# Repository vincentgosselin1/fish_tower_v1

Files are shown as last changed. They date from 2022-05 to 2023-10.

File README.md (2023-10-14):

# fish_tower_v1
fish_tower_v1\
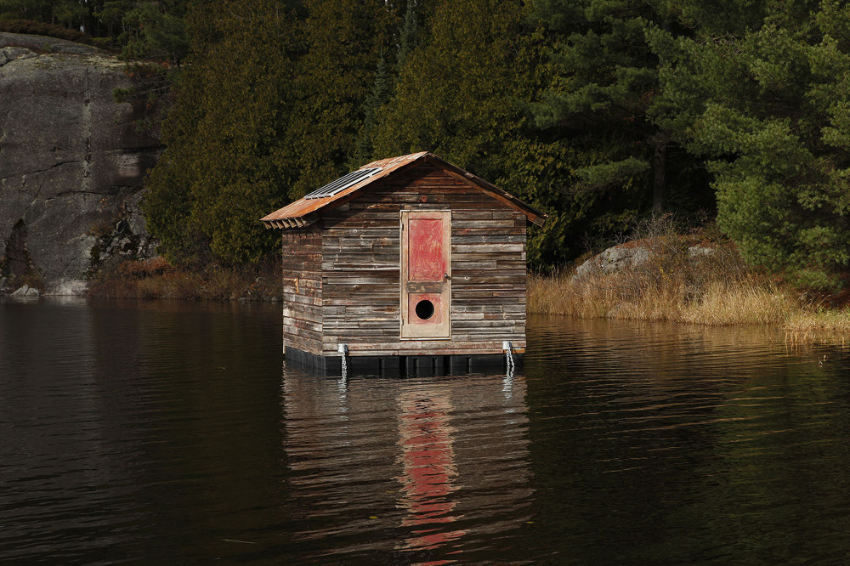
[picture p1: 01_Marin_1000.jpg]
\
all details in https://www.carlmarin.com/Meeting-Point \
Electronic circuit inside : \
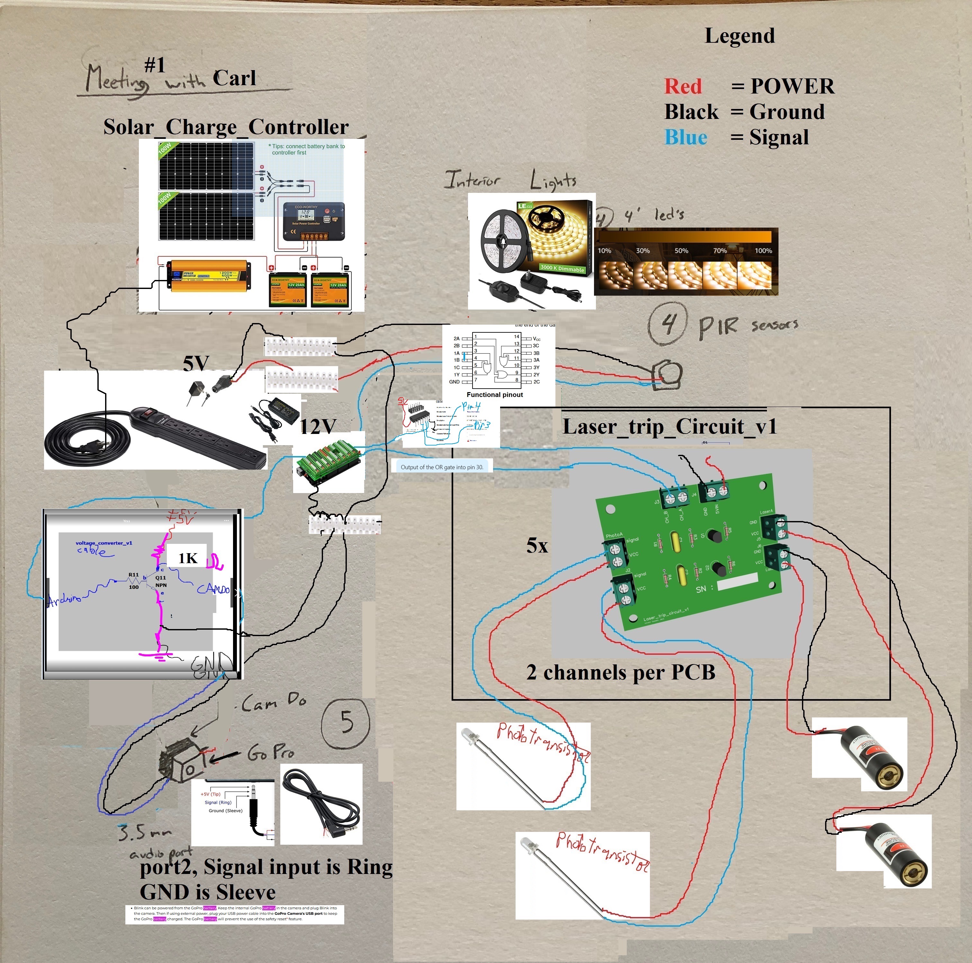
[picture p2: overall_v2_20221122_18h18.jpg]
 \
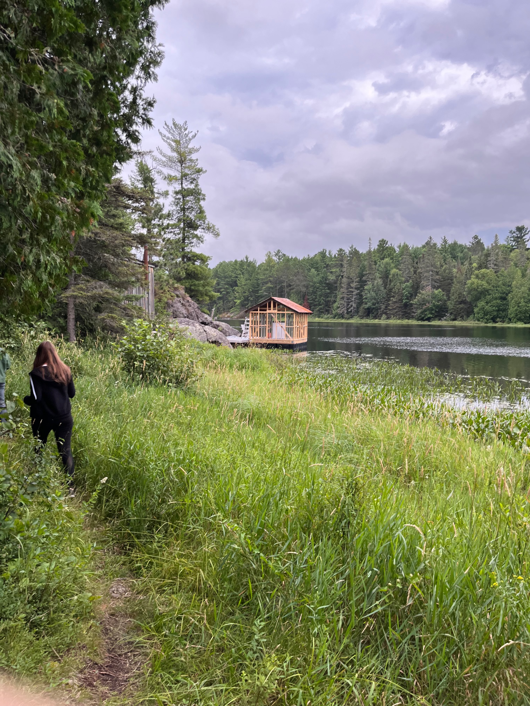
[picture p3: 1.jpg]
 \
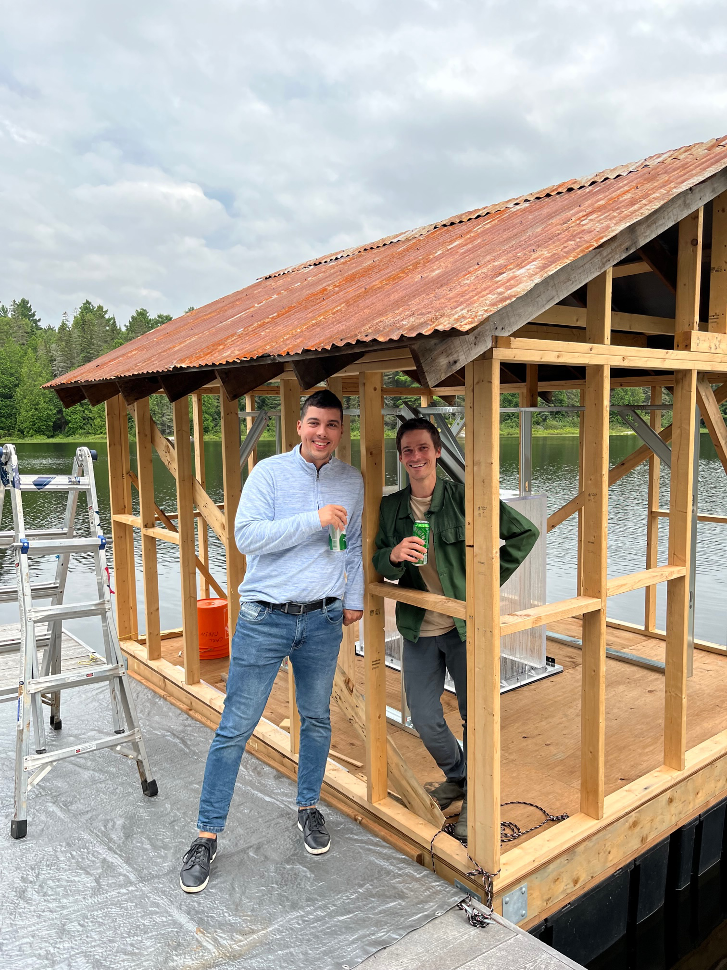
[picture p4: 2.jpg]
 \
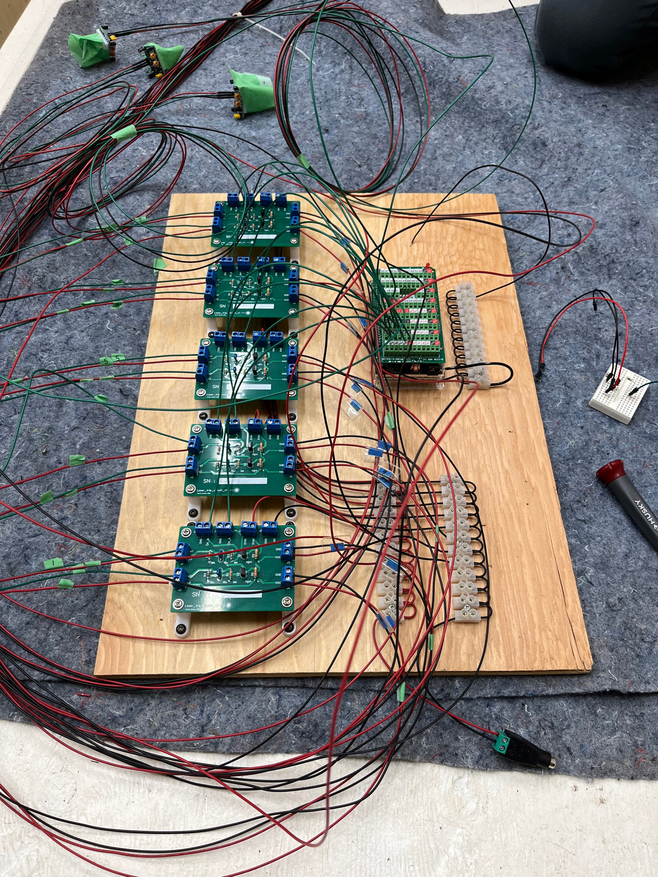
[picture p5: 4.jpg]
 \
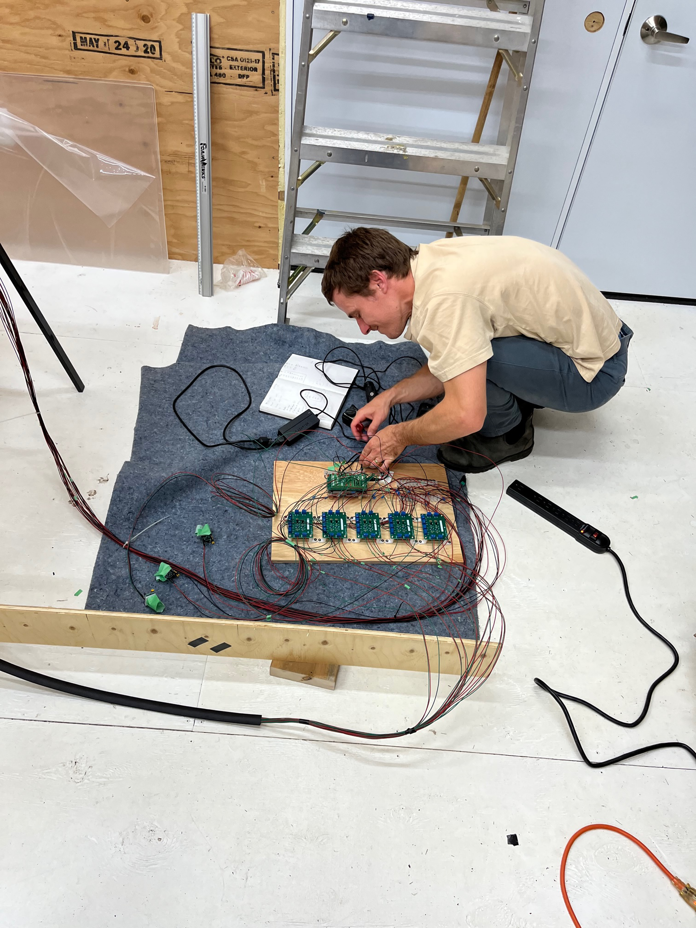
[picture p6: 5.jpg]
 \

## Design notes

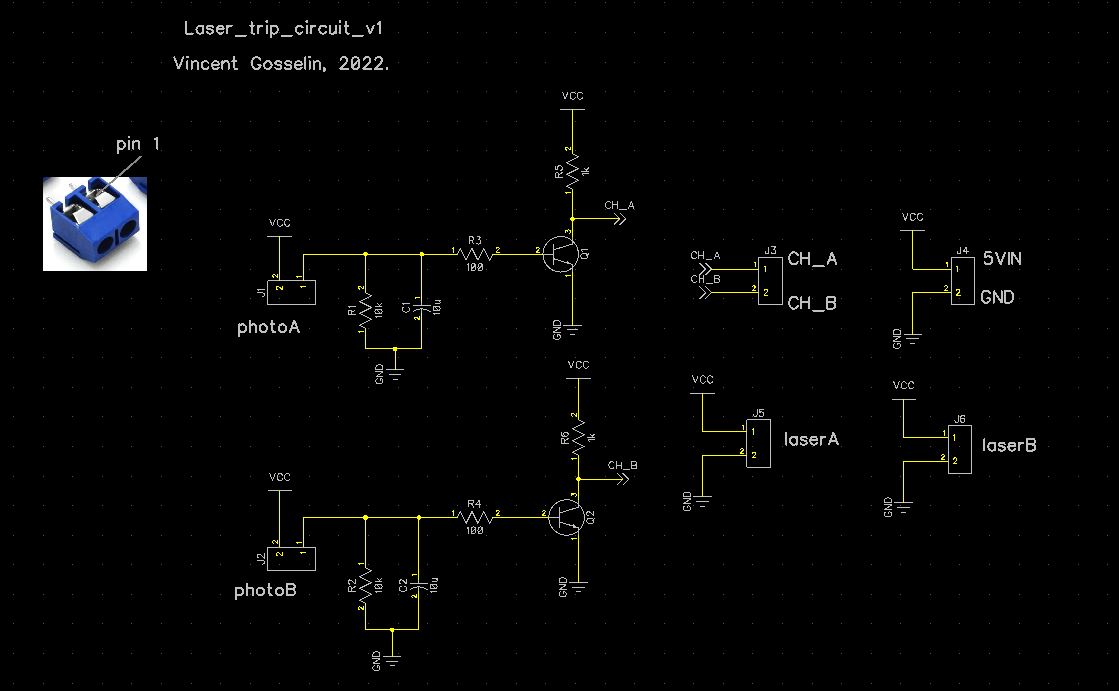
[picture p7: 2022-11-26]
Laser_trip_circuit_v1/laser_trip_circuit_v1_SCHEMATIC.JPG

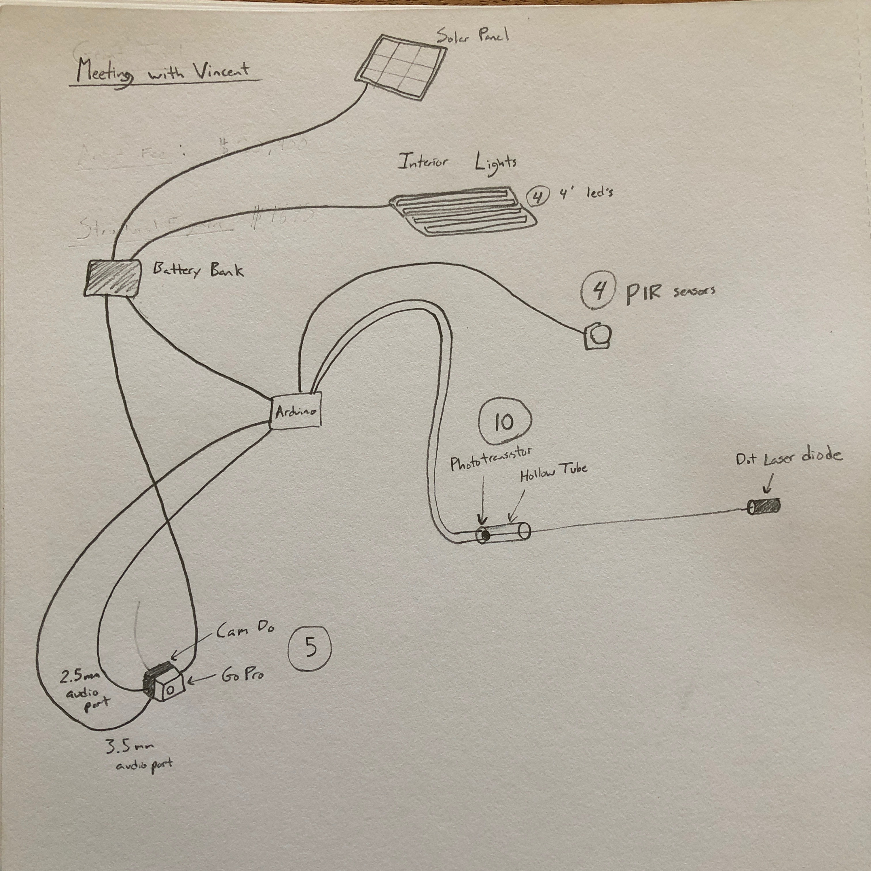
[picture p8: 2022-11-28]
goodtimes/Carl_design.jpeg

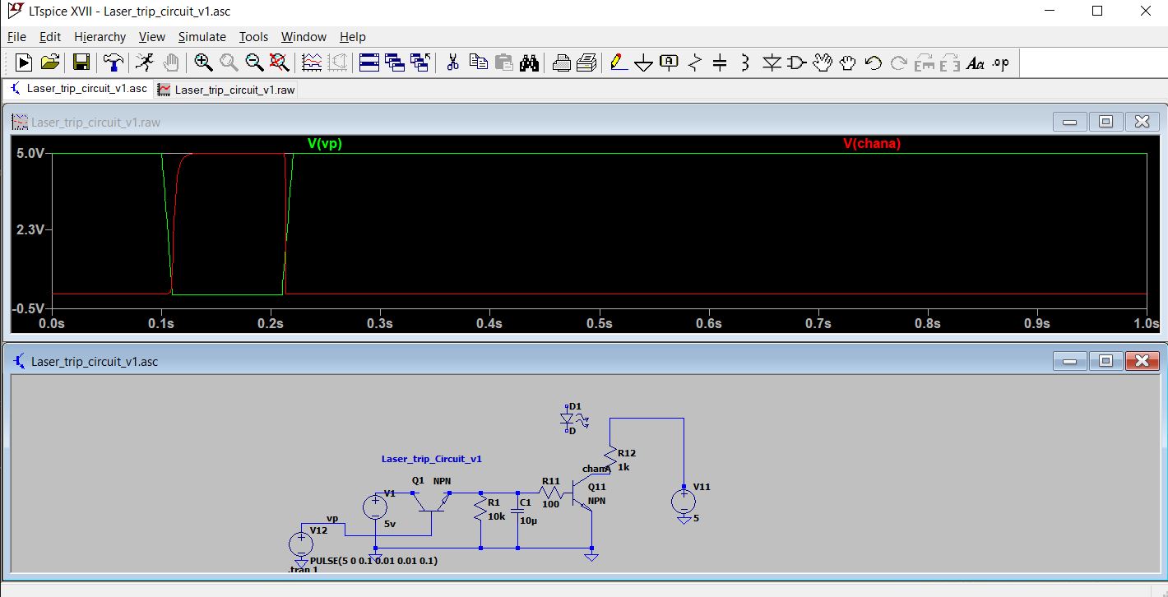
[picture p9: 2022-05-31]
Laser_trip_circuit_v1.JPG

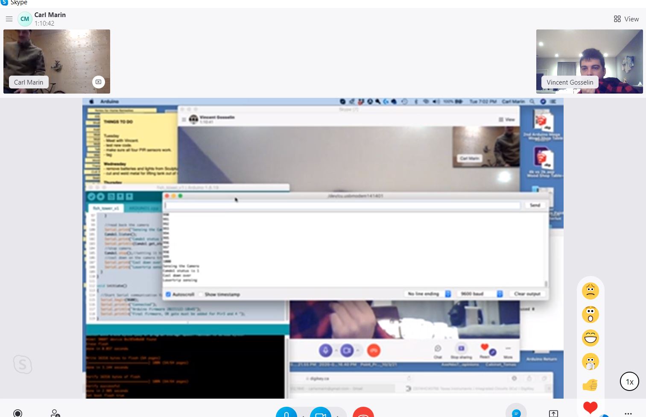
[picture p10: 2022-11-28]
goodtimes/goodtimes5.JPG

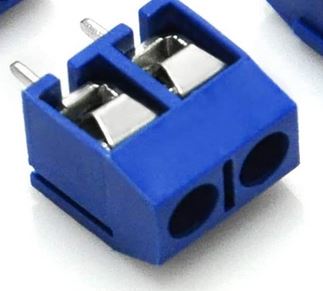
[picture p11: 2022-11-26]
Laser_trip_circuit_v1/pic1.JPG

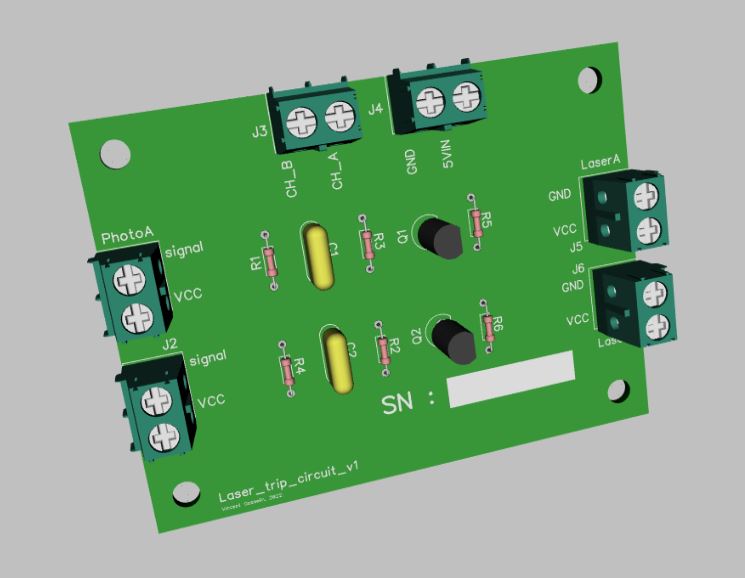
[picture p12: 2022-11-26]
Laser_trip_circuit_v1/laser_trip_circuit_v1_3d.JPG

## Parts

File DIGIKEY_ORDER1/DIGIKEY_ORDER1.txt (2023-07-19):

#DIGIKEY_ORDER1
#CART LINK : https://www.digikey.ca/short/zj1rfh8n

1. Phototransistor : 1080-1019-ND x20
2.  red laser : 		1528-1391-ND x11
2.1 resistor 100 : A105980CT-N
3.  resistors 1k : check	
4.  resistors 10k : check 
5.  capacitor 1uF :  check
6.  capacitor 10uF : check
7.  buzzer :   check
7.1 Arduino Mega : (Amazon order)

8.  potentiometer 1k : check 

9.  ON/OFF switch : check 

11. 5VDC Brick barrel: check

10. phenix terminal bloc : (todo)

11. Laptop 12VDC Brick barrel: (not sure)

11.1 dc barel jack to wires : (check)
12. jumper wires male/male (not sure)

13. variable temperature soldering iron (check)
14. Tin metal : (check)

15. npn transistors : (check)
15. diodes. (check)
16. 12V to 9V DC regulator (todo)
16.1 12V to 5V DC regultator (todo)

17. cable shrink (check)
18. leds  (check)
19.  simple solid core wire 22 awg. (check)
	-> Blue (green instead)
	-> Black
	-> Red

20. electrical tape (check)

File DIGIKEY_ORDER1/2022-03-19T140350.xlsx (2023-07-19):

Index | Quantity | Part Number | Manufacturer Part Number | Description | Customer Reference | Available | Backorder | Unit Price | Extended Price CAD
1 | 20 | 1080-1019-ND | ALS-PT204-6C/L177 | SENSOR PHOTO 630NM RADIAL |  | 20 | 0 | 0.582 | 11.64
2 | 11 | 1528-1391-ND | 1054 | LASER DIODE 650NM 5MW 10MM DIA |  | 11 | 0 | 8.72 | 95.92
3 | 50 | A105980CT-ND | CFR16J100R | RES 100 OHM 5% 1/4W AXIAL |  | 50 | 0 | 0.064 | 3.20
4 | 50 | 1.0KQBK-ND | CFR-25JB-52-1K | RES 1K OHM 5% 1/4W AXIAL |  | 50 | 0 | 0.0534 | 2.67
5 | 50 | 10KEBK-ND | CFR-12JB-52-10K | RES 10K OHM 5% 1/6W AXIAL |  | 50 | 0 | 0.059 | 2.95
6 | 15 | 490-9146-1-ND | RDER71H105K2M1H03A | CAP CER 1UF 50V X7R RADIAL |  | 15 | 0 | 0.623 | 9.35
7 | 15 | 445-FK26X7R1E106K-ND | FK26X7R1E106K | CAP CER 10UF 25V X7R RADIAL |  | 15 | 0 | 0.707 | 10.61
8 | 3 | 445-5242-1-ND | PS1440P02BT | BUZZER PIEZO 3V 14MM TH |  | 3 | 0 | 1.01 | 3.03
9 | 3 | 987-1736-ND | P160KNPD-4QA15A5K | POT 5K OHM 1/10W PLASTIC LOG |  | 3 | 0 | 1.18 | 3.54
10 | 3 | EG5693-ND | RR3112ABLKBLKNFF0 | SWITCH ROCKER SPST 16A 125V |  | 3 | 0 | 1.8 | 5.40
11 | 1 | 839-1662-ND | 16-00019 | AC/DC WALL MOUNT ADAPTER 5V 5W |  | 1 | 0 | 11.74 | 11.74
12 | 1 | 1568-1510-ND | PRT-10288 | ADAPT TERM BL 2POS TO 2.1MM JCK |  | 1 | 0 | 4.06 | 4.06
13 | 1 | 19-165BK4A-ND | 165BK4A | TAPE ELECTRICAL BK 3/4"X 60' |  | 1 | 0 | 4.66 | 4.66
14 | 1 | 1175-2668-50-ND | 10982-22-1-2000-001-1-TD | HOOK-UP SOLID 22AWG 300V BLK 50' |  | 1 | 0 | 11.62 | 11.62
15 | 1 | 1175-2683-50-ND | 10982-22-1-2000-007-1-TD | HOOK-UP SOLID 22AWG 300V GRN 50' |  | 1 | 0 | 11.62 | 11.62
16 | 1 | 1175-2669-50-ND | 10982-22-1-2000-004-1-TD | HOOK-UP SOLID 22AWG 300V RED 50' |  | 1 | 0 | 11.62 | 11.62
17 | 1 | 2260-AO469-ND | AO469 | 60 WATT SOLDERING STATION |  | 1 | 0 | 43.57 | 43.57
18 | 2 | RASW.031.7OZ-ND | RASW.031 .7OZ | SOLDER WIRE POCKET PACK 63/37 TI |  | 2 | 0 | 6.47 | 12.94
19 | 20 | PN2222AFS-ND | PN2222ABU | TRANS NPN 40V 1A TO92-3 |  | 20 | 0 | 0.383 | 7.66
20 | 10 | 754-1807-ND | WP7113VBC/D | LED BLUE CLEAR T-1 3/4 T/H |  | 10 | 0 | 0.525 | 5.25
21 | 1 | Q2Z1-KIT-ND | Q2-Z-QK1-01-6IN-180 | HEATSHRNK KIT 6" 3/64-1/4" 180PC |  | 1 | 0 | 35.64 | 35.64
22 | 1 | 243-1183-ND | 17536 | DESOLDER PUMP WITH TIP 7.5" |  | 1 | 0 | 10.85 | 10.85

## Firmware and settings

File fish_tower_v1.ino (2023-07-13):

/* 
fish_tower_v1.ino, Vincent Gosselin 2023.

FishTower project. 

Target hardware : Arduino Due

Description:

There are 10x laser_trip_circuit hooked to the arduino
to trigger the 5x Camdoo cameras. The Camdoo camera have a feedback signal.
The cameras can also be triggered by 5x PIR sensors. 


Version: 1.o

boot up sequence should be
1. 12V
2. USB cable
3. 5V
4. Camdoo

*/

#include "ARDUINO1.h"
#include "arduinotools.h"

//ALL CLASSES ARE FROM ARDUINO1

//Components
Lasertrip Lasertrip1A(13); //pin13 lasertrip pcb1 with channel A.
Lasertrip Lasertrip1B(12); //pin12 lasertrip pcb1 with channel B.
Lasertrip Lasertrip2A(11); 
Lasertrip Lasertrip2B(10); 
Lasertrip Lasertrip3A(9);
Lasertrip Lasertrip3B(8);
Lasertrip Lasertrip4A(7);
//Lasertrip Lasertrip4B(6);
//Lasertrip Lasertrip5A(5);
Lasertrip Lasertrip5B(4);

Camdo Camdo1(35,37); //Camdo #1, pin 35 trigger 3.5mm , pin 37 feedback 2.5mm.

//PIR_sensor PIR_sensor1(28);
//PIR_sensor PIR_sensor2(29);
//PIR_sensor PIR_sensor3(30);

SmartWait SmartWait1;

void setup()
{
  initiate();
}

void loop()
{
  //turn OFF camdoo
  Camdo1.stop();
  
  //listen to lasertrip circuits
  Lasertrip1A.listen();
  Lasertrip1B.listen();
  Lasertrip2A.listen();
  Lasertrip2B.listen();
  Lasertrip3A.listen();
  Lasertrip3B.listen();
  Lasertrip4A.listen();
  //Lasertrip4B.listen();
  //Lasertrip5A.listen();
  Lasertrip5B.listen();
  //PIR_sensor1.listen();
  //PIR_sensor2.listen();
  //PIR_sensor3.listen();
  
  //Did an event happenned?
    if(    Lasertrip1A.get_status() || Lasertrip1B.get_status() 
	   || Lasertrip2A.get_status() || Lasertrip2B.get_status() 
	   || Lasertrip3A.get_status() || Lasertrip3B.get_status()
	   || Lasertrip4A.get_status() || Lasertrip5B.get_status()
	   //|| PIR_sensor1.get_status() || PIR_sensor2.get_status()
	   //|| PIR_sensor3.get_status() 
         ){
    
    //a fish was detected! 
    Serial.print("a fish was detected!, laser tripped!  \n\r");
    //activate the camera
    Serial.print("Activating the Camera \n\r");
    Camdo1.run();//setting it low
    
    int i = 0;
    while(i<1000){
      i++;
      Serial.println(i, DEC);
    }
    
    //read back the camera
    Serial.print("Sensing the Camera \n\r");
    Camdo1.listen();
    Serial.print("Camdo1 status is ");
    Serial.println(Camdo1.get_status());
    //stop camera.
    Camdo1.stop();//setting it high
    //cool down on the camera trigger
    delay(210000);//3 mins 30 seconds
    Serial.print("Cool down over \n\r");
    Serial.print("Lasertrip sensing \n\r");
  }
}

void initiate()
{
	//Start Serial communication for debugging.
	Serial.begin(9600);
	Serial.println("Connected");
	Serial.println("Arduino firmware 20230712-19h59");
	Serial.println("pir sensors and laser4B/5A de-activated");
}

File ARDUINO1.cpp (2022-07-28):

//GROWBOX1 Library, defitions of class.
//Growbox1_arduinodue Software by Vincent Gosselin, copyright 2016.	

//This File should copied to Documents/Arduino/Libraries/GROWBOX1/GROWBOX1.cpp for changes to happen in the Arduino.


//#include "Arduino.h"
#include "ARDUINO1.h"
//Digital pin class.
Digital_pin::Digital_pin(int pin)
{
	_pin=pin;
	_state=0;//LOW at init.
	_previousMillis=0;//0 a start;
}
bool Digital_pin::get_state()
{
	return _state;
}
void Digital_pin::set_input()
{
	pinMode(_pin,INPUT);
}
void Digital_pin::set_input_pullup()
{
	pinMode(_pin,INPUT_PULLUP);
}
void Digital_pin::set_output()
{
	pinMode(_pin,OUTPUT);
}
void Digital_pin::high()
{
	digitalWrite(_pin,1);
	_state=1;
}
void Digital_pin::low()
{
	digitalWrite(_pin,0);
	_state=0;
}
void Digital_pin::blink()
{
	unsigned long currentMillis = millis();
	if(currentMillis - _previousMillis >= 300)
	{
		_previousMillis = currentMillis;
		digitalWrite(_pin,_state);
		_state=!_state;
	}
	else;
}
void Digital_pin::init()
{
	set_output();
	low();
}
bool Digital_pin::read_input()
{
	bool state;
	state = digitalRead(_pin);
	_state = state;
	return state;
}
//led class
led::led(int pin)
{
	_pin = new Digital_pin(pin);//Creating object Digital_pin.
	_pin->set_output();//Pin will be an output.
	_pin->low();//puts pin to ground
	_state = 0;
}
void led::on()
{
	_pin->high();
	_state = 1;
}
void led::off()
{
	_pin->low();
	_state = 0;
}
//Pushbutton class
Pushbutton::Pushbutton(int pin)
{
	_pin = new Digital_pin(pin);//Creating object Digital_pin.
	_pin->set_input_pullup();
	_state = 1;//Off by default.
}
void Pushbutton::set_state()
{
	bool state = _pin->read_input();// ON is 0 (Grounded), OFF is 1 (OPEN)
	_state = state;
}
bool Pushbutton::get_state()
{
	return _state;
}
//Switch class
Switch::Switch(int pin)
{
	_pin = new Digital_pin(pin);//Creating object Digital_pin.
	_pin->set_input_pullup();
	_status = 1;//Off by default.
}
void Switch::listen()
{
	bool status = _pin->read_input();// ON is 0 (Grounded), OFF is 1 (OPEN)
	//The following is to avoid the switch bouncing.
	if(_status != status)
	{
		//Wait for switch to debounce.
		delay(500);
		//Another reading since oscillation is done.
		status = _pin->read_input();
	}
	_status = status;
}
bool Switch::get_status()
{
	return _status;
}
//Switch3WAY class
Switch3WAY::Switch3WAY(int pinA, int pinB)
{
	_pinA = new Digital_pin(pinA);//Creating object Digital_pin.
	_pinA->set_input_pullup();
	_pinB = new Digital_pin(pinB);//Creating object Digital_pin.
	_pinB->set_input_pullup();
	_position = 'A';//Default
}
void Switch3WAY::listen()
{
	char position;
	bool tempA = _pinA->read_input();
	bool tempB = _pinB->read_input();

	if(tempA==0 && tempB == 1){ position = 'A';}
	if(tempA==1 && tempB == 0){ position = 'B';}
	if(tempA==1 && tempB == 1){ position = 'C';}

	_position = position;
}
char Switch3WAY::get_position()
{
	return _position;
}
analog_pin::analog_pin(int pin)
{
	_pin=pin;
}
int analog_pin::read_adc()
{
	return analogRead(_pin);
}
timer::timer(const char * array)
{
//Separate the char array and converts into seconds
	int days = (array[0] - '0')*10 + (array[1] - '0');//for days.
	int hours = (array[3] - '0')*10 + (array[4] - '0');//for hours.

	int minutes = (array[6] - '0')*10 + (array[7] - '0');//for minutes.
	int seconds = (array[9] - '0')*10 + (array[10] - '0');//for seconds.
//_preset gets initialized to the preset.
 	_preset = days*24*3600 + hours*3600 + minutes*60 + seconds;
	_previousMillis = 0;//no previous Millis.
	_status = 0;//Timer doesn't run at start.
	_done = 0;//Timer not done.
	_ready_to_count=0;//Used in the on_for functions of each classes.
//Reset timer at init.	
	reset();//Reset timer at init.
// Init array
	_countarray = new char[12];	
	for(int i=0; i<12; i++)
	{
		_countarray[i] = '0';
	}
}

unsigned long timer::get_count()
{
	return _count;
}
char * timer::get_count_string()
{
//getting nb of days, hours, minutes, seconds.	
 	unsigned long count = _count;//in seconds.
	//nb of days, hours, minutes, seconds. all init at 0.
	int days=0;
	int hours=0;
	int minutes=0;

	//days nb.
	while(count>=24*3600)
	{
		count=count-(24*3600);
		days++;
	}
	//hours nb.
	while(count>=3600)
	{
		count=count-(3600);
		hours++;
	}
	//minutes nb.
	while(count>=60)
	{
		count=count-(60);
		minutes++;
	}
	//Count is in sec now.


//Building up _countarray
	int temp=0;
	while(days>=10)
	{
		days=days-10;
		temp++;
	}
	_countarray[0]= temp + '0';
	_countarray[1]=days + '0';
	_countarray[2]='d';
	temp=0;//Yes, I'm ready to do it again my master....
	while(hours>=10)
	{
		hours=hours-10;
		temp++;
	}
	_countarray[3]=temp+'0';
	_countarray[4]=hours + '0';
	_countarray[5]='h';
	temp=0;//PLEASE SOMEONE HELP ME.
	while(minutes>=10)
	{
		minutes=minutes-10;
		temp++;
	}
	_countarray[6]=temp+'0';
	_countarray[7]=minutes +'0';
	_countarray[8]='m';
	temp=0;//Ok, this is better be the last one...
	while(count>=10)
	{
		count=count-10;
		temp++;
	}	
	_countarray[9]=temp+'0';
	_countarray[10]=count+'0';
	_countarray[11]='s';


return _countarray;
}
bool timer::get_status()
{
	return _status;
}
bool timer::get_done()
{
	return _done;
}
bool timer::get_ready_to_count()
{
	return _ready_to_count;
}
void timer::set_ready_to_count(bool set)
{
	_ready_to_count=set;
}
void timer::reset()
{
	_count=_preset;//
	_done=0;
	_status=0;
}
void timer::run()
{
	if(_count>0)//timer is not done.
	{
		_status = 1;
		unsigned long currentMillis = millis();
		//Condition to break overflow that happens after 50days when previousmillis is greater than currentmillis.
		if(_previousMillis > currentMillis)
		{
			_previousMillis = 0;
		}
		//Counts 1 sec.
		if(currentMillis - _previousMillis >= 1000)//1000ms = 1sec.
		{
			//Count my dear.
 			_count--;
 			_previousMillis=currentMillis;            
		}
		else;//do nothing.
	}
	else//timer is done.
	{	
	_status = 0;
	_done = 1;
	}
}
void timer::serialprint()
{
	Serial.println(get_count_string());
}
void timer::init(char * array)
{
	//Separate the char array and converts into seconds
	int days = (array[0] - '0')*10 + (array[1] - '0');//for days.
	int hours = (array[3] - '0')*10 + (array[4] - '0');//for hours.

	int minutes = (array[6] - '0')*10 + (array[7] - '0');//for minutes.
	int seconds = (array[9] - '0')*10 + (array[10] - '0');//for seconds.
	//_preset gets initialized to the preset.
 	_preset = days*24*3600 + hours*3600 + minutes*60 + seconds;
	_previousMillis = 0;//no previous Millis.
	_status = 0;//Timer doesn't run at start.
	_done = 0;//Timer not done.
	//Reset timer at init.	
	reset();//Reset timer at init.
}
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

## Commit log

2022-05-31 to test the circuit
2022-06-23 lasertrip.listen super sensible
2022-06-29 arduino due
2022-07-27 all the lasertripcircuits
2022-07-28 polarity inverted because of the transistor circuit
    [fish_tower_v1.ino]
2022-07-29 another pin
2022-11-01 pir sensors not firing camera
2022-11-26 adding gerbers/stuff
    [1 - Top.gbr, 2 - Bottom.gbr, BoardOutline.gbr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]
2023-07-19 digikey order
    [2022-03-19T140350.xlsx]
